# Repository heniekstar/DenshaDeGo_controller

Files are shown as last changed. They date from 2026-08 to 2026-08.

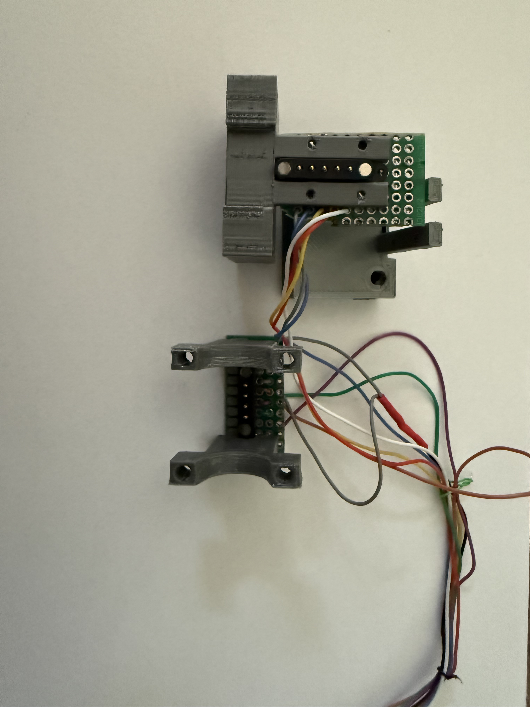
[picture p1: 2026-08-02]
pics/POGO_1.JPG

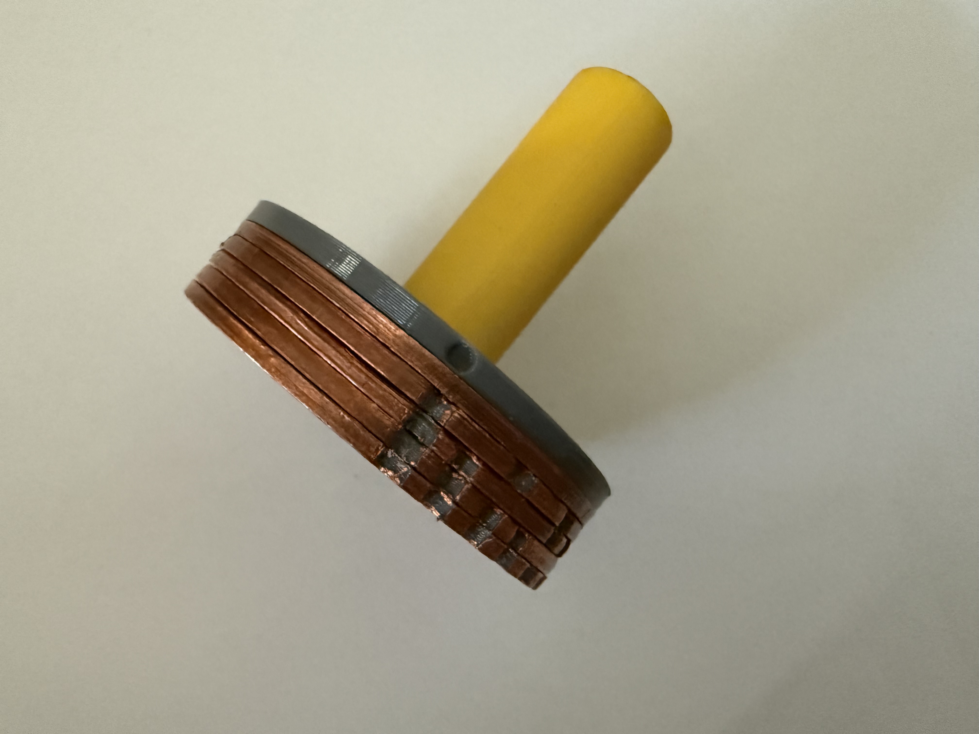
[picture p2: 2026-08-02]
pics/POGO_BREAK_WHEELS_2.JPG

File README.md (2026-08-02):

# DenshaDeGo_controller


3d printed recreation of Densha de Go! train controller using limit switches or pogo pins. 
Please remind: This is not a perfect controller. I've made this controller as a test for myself. 
I've made it also because I want to experience Densha de Go! on train controller and not on gamepad. 
Controller have some issues that require some additional work but I don't know if I could solve them.
I think this may bring new peoples to this games as it's lowers a barrier of entry.
Feel free to modify this controller

This could not be possible without Train controller database: https://traincontrollerdb.marcriera.cat/index.html

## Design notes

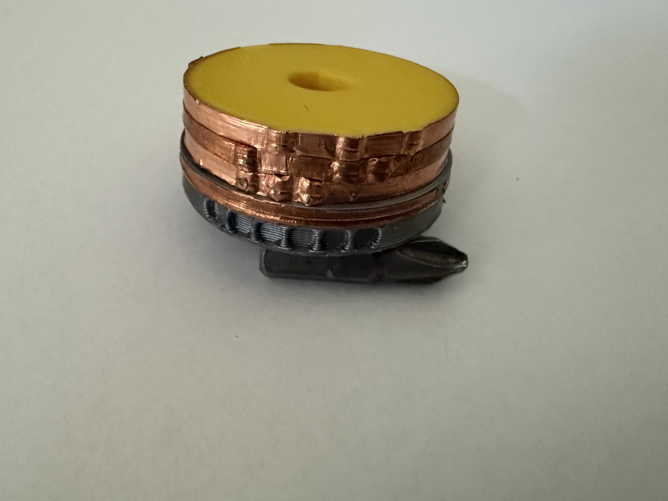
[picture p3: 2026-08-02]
pics/POGO_POWER_WHEELS_1.JPG

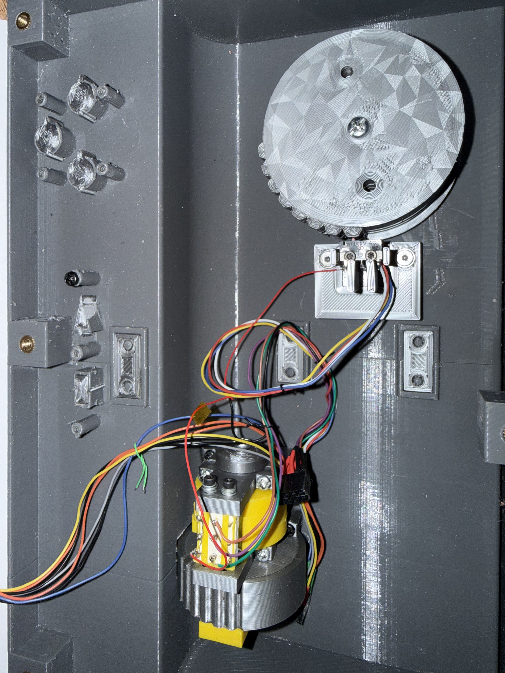
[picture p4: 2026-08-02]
pics/LIMIT_SWITCHES.JPG

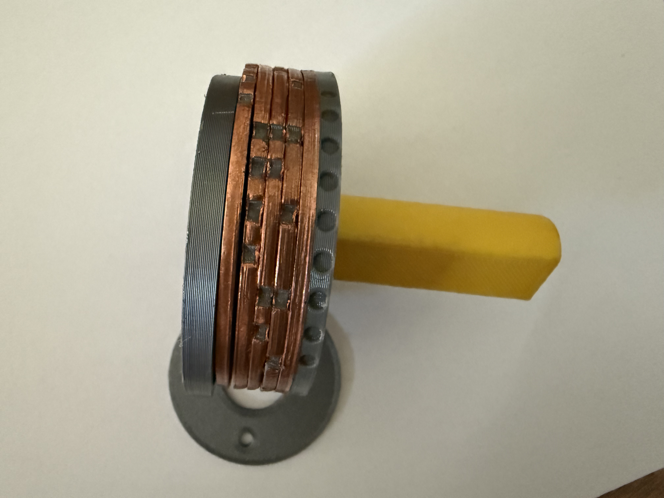
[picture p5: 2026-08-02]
pics/POGO_BREAK_WHEELS_1.JPG

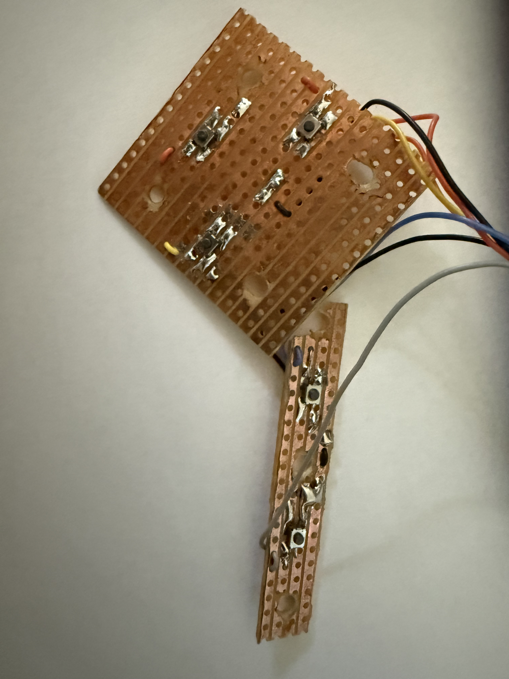
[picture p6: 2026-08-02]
pics/BUTTONS_PCBs.JPG

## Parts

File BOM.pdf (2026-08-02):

### BOM for End switch version

Id. Name | Pcs.
1. DDG_BREAK_SHAFT | 1
2. DDG_BRAKE_WHEEL_HAPTIC | 1
3. DDG_BRAKE_WHEEL_1 | 1
4. DDG_BRAKE_WHEEL_2 | 1
5. DDG_BRAKE_WHEEL_3 | 1
6. DDG_BRAKE_WHEEL_4 | 1
7. DDG_BREAK_HANDLE | 1
8. DDG_BREAK_HANDLE_BARREL | 1
9. DDG_BRAKE_SWITCH_HOUSING | 1
10. DDG_BREAK_SWITCH_HAPTIC | 1
11. DDG_POWER_SHAFT | 1
12. DDG_POWER_RING | 1
13. DDG_POWER_HANDLE_WHEEL | 1
14. DDG_POWER_WHEEL_1 | 1
15. DDG_POWER_WHEEL_2 | 1
16. DDG_POWER_WHEEL_3 | 1
17. DDG_POWER_END_CAP | 2
18. DDG_POWER_SWITCH_HOUSING | 1
19. DDG_TOP_HOUSING | 1
20. DDG_TOP_POWER_LOWER_SUPPORT | 3
21. DDG_POWER_ASSEMBLY | 1
22. DDG_TOP_POWER_UPPER_SUPPORT | 3
23. DDG_POWER_SWITCH_ASSEMBLY | 1
24. DDG_BREAK_ASSEMBLY | 1
25. DDG_BREAK_SWITCH_ASSEMBLY | 1
26. DDG_TOP&BOT_LINK | 4
27. DDG_POWER_HANDLE_ANGLE | 1
28. DDG_POWER_HANDLE_END_CAP | 1
29. DDG_TOP_SELECT _BUTTON | 1
30. DDG_TOP_START_BUTTON | 1
31. DDG_TOP_A_BUTTON | 1
32. DDG_TOP_B_BUTTON | 1
33. DDG_TOP_C_BUTTON | 1
34. DDG_BOTTON_SHELL | 1
35. DDG_BOT_STR_SEL_LINK | 1
36. DDG_TOP&BOT_LINK | 4
37. DDG_POWER_HAPTIC_HOLDER | 1
38. DDG_POWER_HAPTIC | 1
39. DDG_BOTTOM_START_SUPPORT | 1
40. DDG_TOP_ASSEMBLY | 1
41. DDG_BOTTOM_ASSEMBLY | 1
42. END SWITCH | 7
43. M4x14 Bolt (PH/PZ/HEX/TX) | 10
44. M2x30 screw with HEX head | 4
45. M2 NUT | 4
46. M2 washer (under head of M2 bolt, 4 per bolt | 12
47. Self-taping screw 3x8 or bolt M3x8 (up to M3x12) | 21
48. M3x12 (Can be shorter) | 9
49. Heat insert M4 | 6
50. Push button 3x4x2 | 6
51. Universal PCB | 1

52.

Thin guage wires (30AWG). They should not be a single core wires (8
colores minimum)

### Additional parts for POGO Version:

1. | DDG_BREAK_SHAFT (same as end switch version) | 1
2. | DDG_BRAKE_WHEEL_HAPTIC (same as end switch version) | 1
3. | DDG_POGO_BREAK_SPACER | 1
4. | DDG_POGO_BREAK_WHEEL_MAG | 2
5. | DDG_POGO_BREAK_WHEEL_0 | 1
6. | DDG_POGO_BREAK_WHEEL_1 | 1
7. | DDG_POGO_BREAK_WHEEL_2 | 1
8. | DDG_POGO_BREAK_WHEEL_3 | 1
9. | DDG_POGO_BREAK_WHEEL_4 | 1
10. DDG_POGO_BREAK_WHEEL_SUPPORT | 1
11. | DDG_BREAK_HANDLE (same as end switch version) | 1
12. DDG_BREAK_HANDLE_BARREL (same as end switch version) | 1
13. DDG_POWER_SHAFT (same as end switch version) | 1
14. DDG_POWER_RING (same as end switch version) | 1
15. DDG_POWER_HANDLE_WHEEL (same as end switch version) | 1
16. DDG_POGO_POWER_WHEEL_MAG | 2
17. DDG_POGO_POWER_WHEEL_0 | 1
18. DDG_POGO_POWER_WHEEL_1 | 1
19. DDG_POGO_POWER_WHEEL_2 | 1
20. DDG_POGO_POWER_WHEEL_3 | 1
21. DDG_POWER_END_CAP | 2
22. 4 pin POGO connector | 1
23. 5 pin POGO connector | 1

### For part number 42 – End switch use 12,8X6X6MM Limit switch. I’ve use this one: https://pl.aliexpress.com/item/1005005596552328.html?gatewayAdapt=glo2pol but this also should work:

https://www.tme.eu/pl/en/details/d2f-01/microswitches-snap-action/omron-electronic-components/

Just search for a limit switch that have the same dimensions.

### The pogo connector I’ve bought from this page: https://pl.aliexpress.com/item/1005010344694119.html?gatewayAdapt=glo2pol

Links to aliexpress are in Polish so adjust language to your country. I’ve ordered this parts long before EU tarfis. Maybe you can find same connectors on other sites.

For a push switch you can use any other design. It may be needed to trim „wings” on the buttons to make them fit.

### For Universal PCB I’ve used this kind of board:

### https://www.tme.eu/pl/en/details/rad-710-5/universal-pcbs/rademacher/710-5/

I’ve used this one because I’ve this one already. You can use other types of PCBs but it’s better to use board with 1.6mm thickness.

For connecting wires use a flexible wires as the are easier to handle inside the housing. I’ve recommend to use at least 8 colours for easier recognition what wire goes where. But I’m no gonna to stop you from using only one color for all cables.

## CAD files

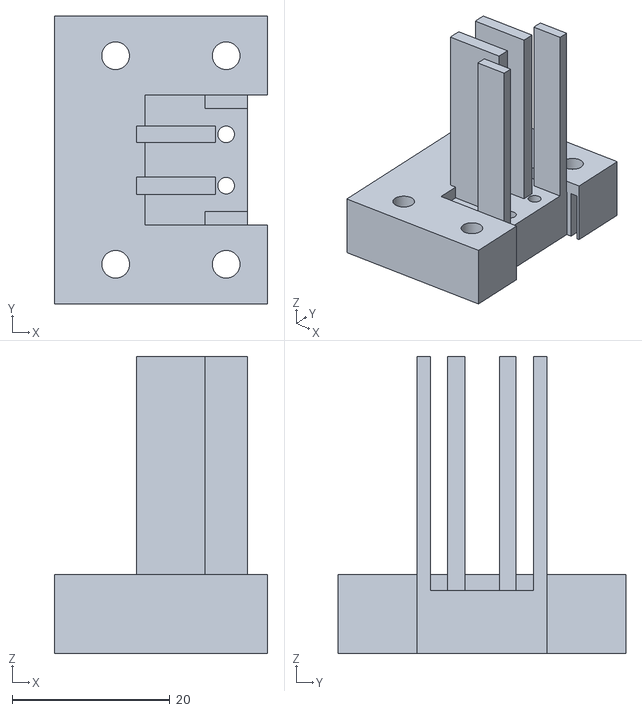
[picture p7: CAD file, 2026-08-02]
Limit_switch/DDG_BRAKE_SWITCH_HOUSING.stl
27.0 x 36.4 x 37.6

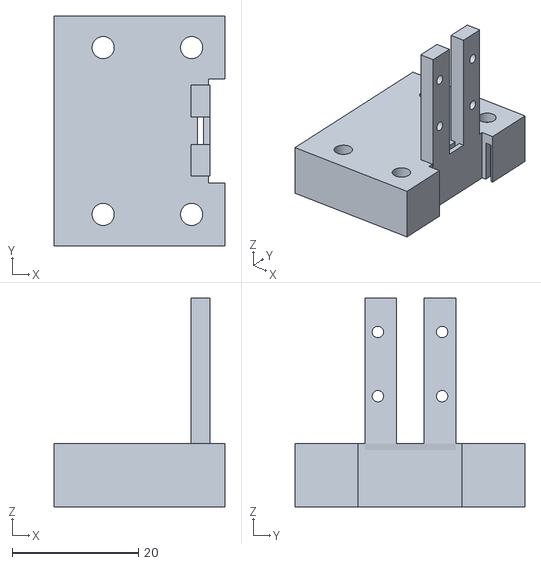
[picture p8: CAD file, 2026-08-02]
Pogo/DDG_POGO_BREAK_HOLDER.stl
27.0 x 36.4 x 33.0

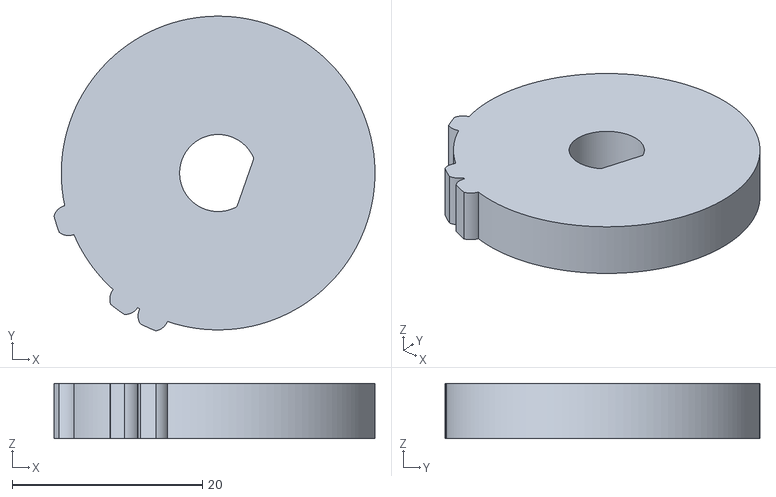
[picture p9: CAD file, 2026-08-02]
Limit_switch/DDG_POWER_WHEEL_2.stl
33.8 x 33.1 x 5.80

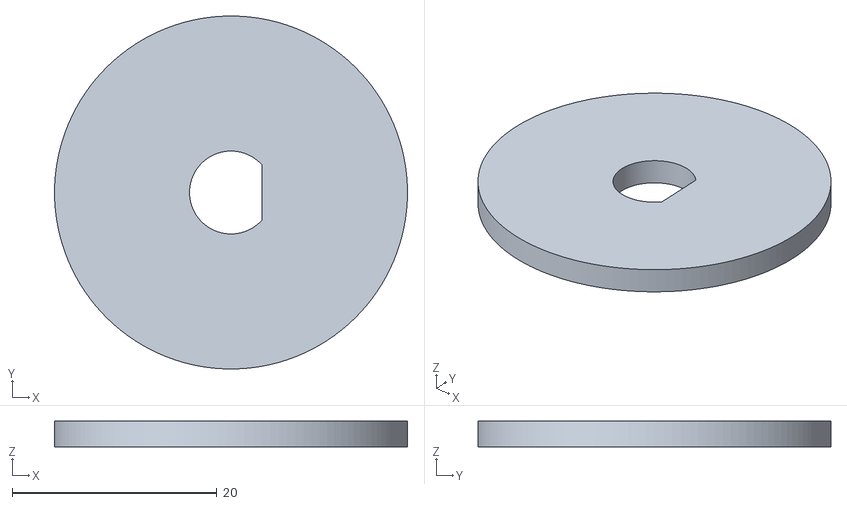
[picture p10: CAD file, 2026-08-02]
Pogo/DDG_POGO_POWER_WHEEL_0.stl
34.5 x 34.5 x 2.50

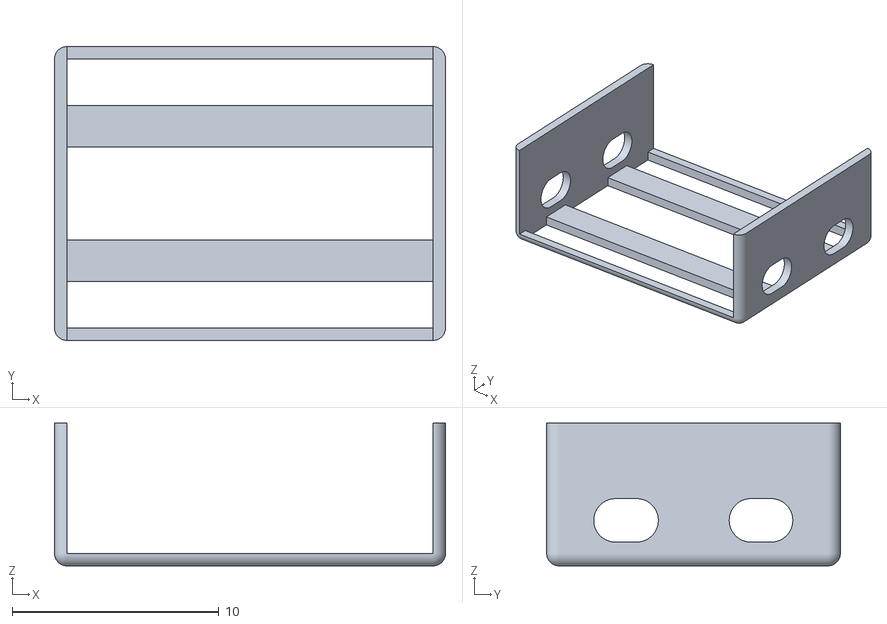
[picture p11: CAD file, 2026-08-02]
Limit_switch/DDG_POWER_SWITCH_HOUSING.stl
18.9 x 14.2 x 6.90

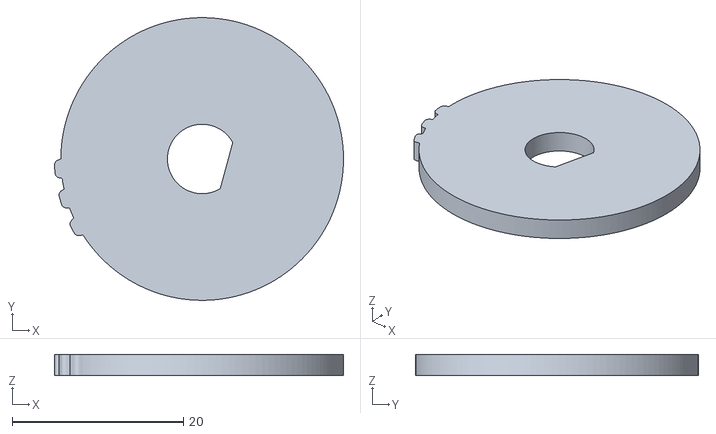
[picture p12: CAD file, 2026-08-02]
Pogo/DDG_POGO_POWER_WHEEL_3.stl
33.7 x 33.0 x 2.50

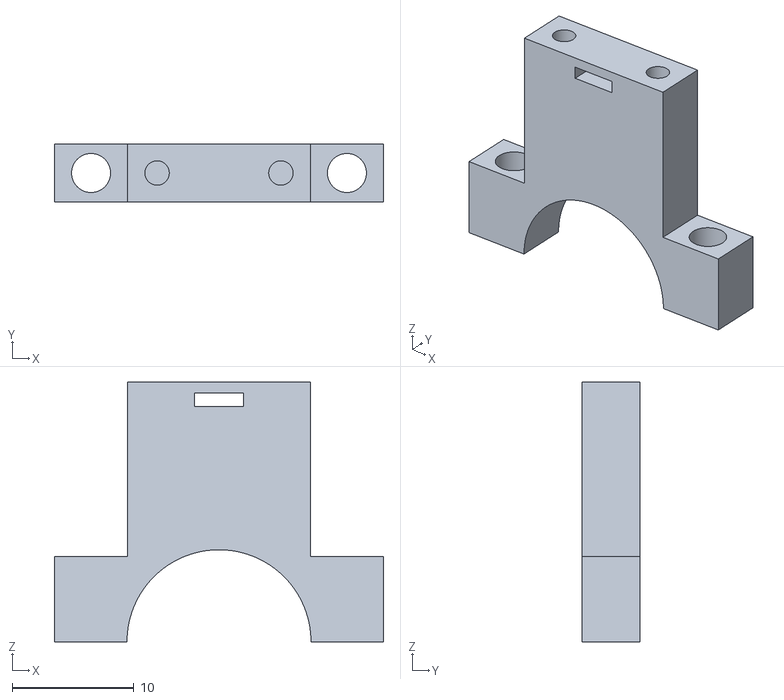
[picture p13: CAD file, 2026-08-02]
Pogo/DDG_POGO_POWER_UPPER_SUPPORT.stl
27.0 x 4.80 x 21.3

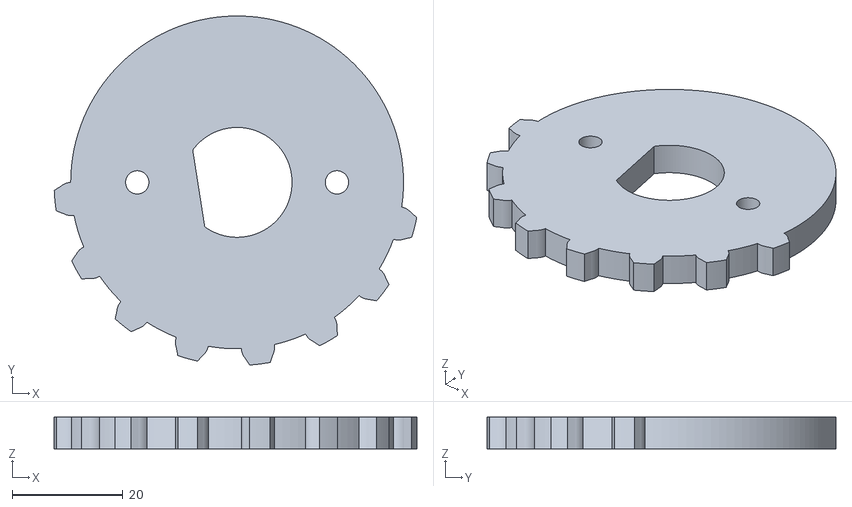
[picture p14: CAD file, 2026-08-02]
Limit_switch/DDG_BRAKE_WHEEL_1.stl
65.4 x 62.9 x 5.70

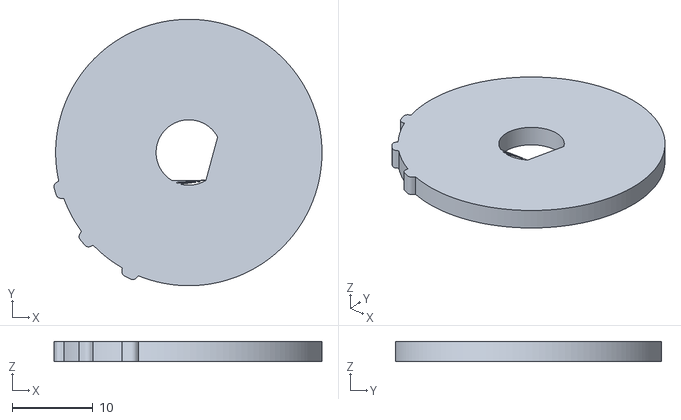
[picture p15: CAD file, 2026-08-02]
Pogo/DDG_POGO_POWER_WHEEL_1.stl
33.2 x 33.0 x 2.50

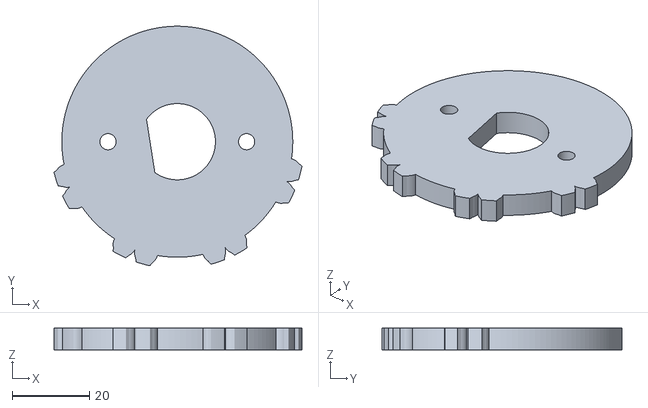
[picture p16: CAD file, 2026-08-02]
Limit_switch/DDG_BRAKE_WHEEL_2.stl
64.4 x 62.2 x 5.70

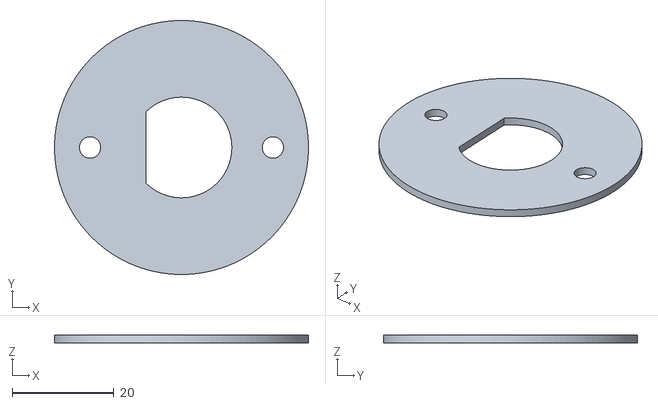
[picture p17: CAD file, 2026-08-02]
Pogo/DDG_POGO_BREAK_SPACER.stl
50.0 x 50.0 x 1.50

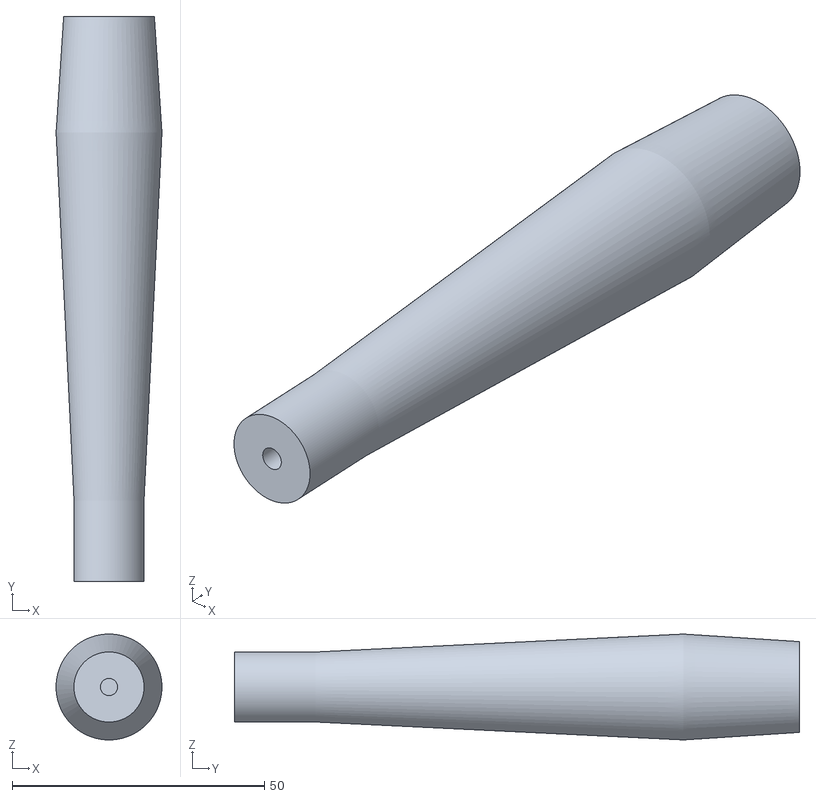
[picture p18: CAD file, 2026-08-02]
Limit_switch/DDG_BREAK_HANDLE.stl
21.0 x 112.0 x 21.0

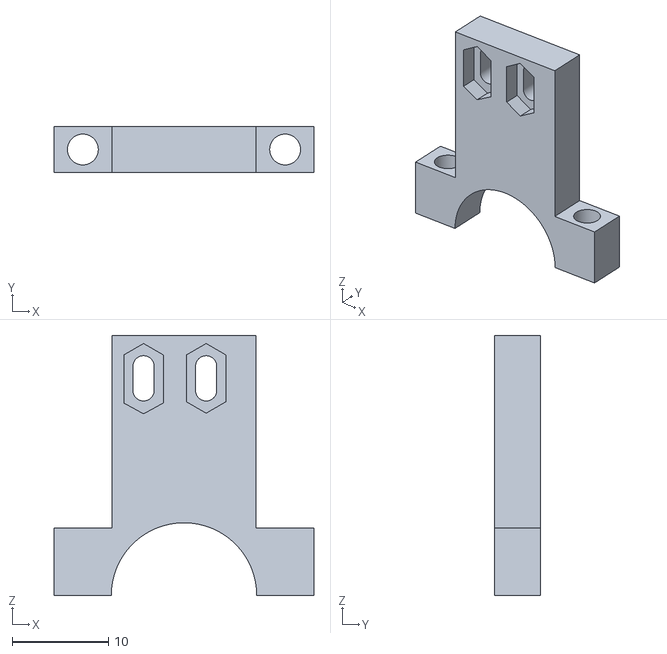
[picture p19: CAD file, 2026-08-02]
Limit_switch/DDG_TOP_POWER_UPPER_SUPPORT.stl
27.0 x 4.80 x 27.0

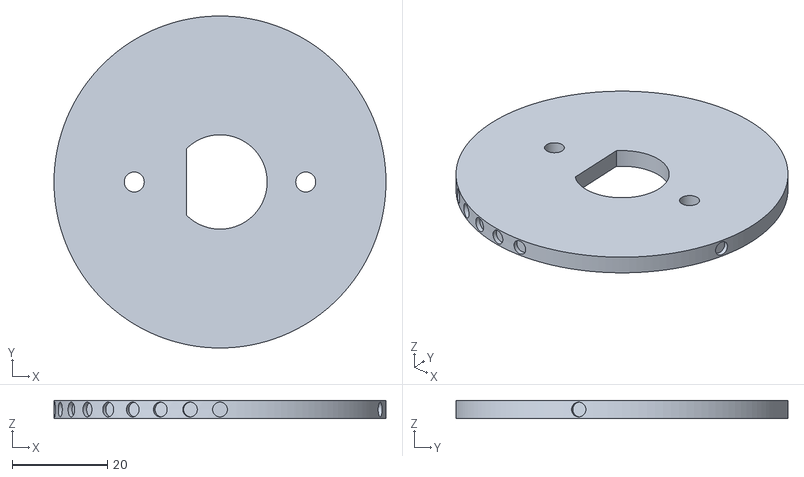
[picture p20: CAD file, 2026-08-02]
Pogo/DDG_POGO_BREAK_WHEEL_MAG.stl
69.7 x 69.7 x 3.80

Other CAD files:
Limit_switch/DDG_POWER_WHEEL_1.stl
Pogo/DDG_POGO_POWER_WHEEL_2.stl
Limit_switch/DDG_BRAKE_WHEEL_3.stl
Pogo/DDG_POGO_BREAK_WHEEL_2.stl
Limit_switch/DDG_BRAKE_WHEEL_4.stl
Limit_switch/DDG_POWER_WHEEL_3.stl
Pogo/DDG_BOTTOM_START_SUPPORT.stl
Pogo/DDG_BOTTON_SHELL-Slice.0.stl
Pogo/DDG_BOTTON_SHELL-Slice.1.stl
Pogo/DDG_BOTTON_SHELL.stl
Pogo/DDG_BOT_STR_SEL_LINK.stl
Pogo/DDG_BRAKE_WHEEL_HAPTIC.stl
Pogo/DDG_BREAK_GUIDE.stl
Pogo/DDG_BREAK_HANDLE_BARREL.stl
Pogo/DDG_BREAK_HANDLE_BARREL_GUIDE.stl
Pogo/DDG_BREAK_SHAFT.stl
Pogo/DDG_BREAK_SWITCH_HAPTIC.stl
Pogo/DDG_POGO_BREAK_WHEEL_0.stl
Pogo/DDG_POGO_BREAK_WHEEL_1.stl
Pogo/DDG_POGO_BREAK_WHEEL_3.stl
Pogo/DDG_POGO_BREAK_WHEEL_4.stl
Pogo/DDG_POGO_BREAK_WHEEL_SUPPORT.stl
Pogo/DDG_POGO_POWER_WHEEL_MAG.stl
Pogo/DDG_POWER_END_CAP.stl
Pogo/DDG_POWER_HANDLE_ANGLE.stl
Pogo/DDG_POWER_HANDLE_END_CAP.stl
Pogo/DDG_POWER_HANDLE_WHEEL.stl
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

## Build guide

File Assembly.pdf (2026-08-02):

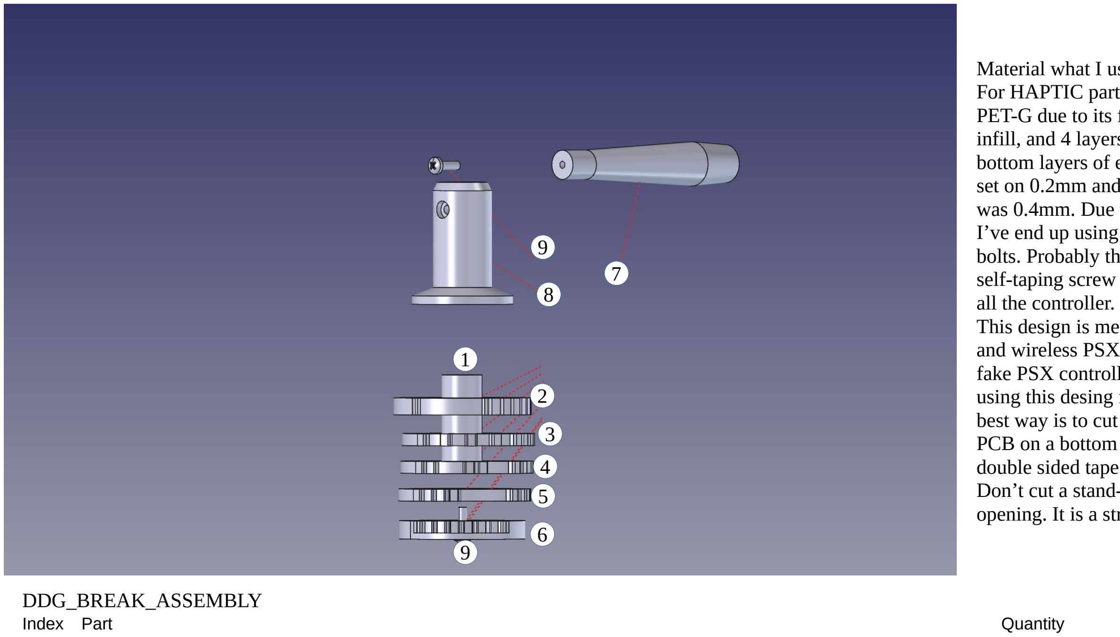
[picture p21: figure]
DDG_BREAK_ASSEMBLY; Index Part; Quantity; all the controller.

1. | DDG_BREAK_SHAFT | 1
2. | DDG_BRAKE_WHEEL_HAPTIC | 1
3. | DDG_BRAKE_WHEEL_1 | 1
4. | DDG_BRAKE_WHEEL_2 | 1
5. | DDG_BRAKE_WHEEL_3 | 1
6. | DDG_BRAKE_WHEEL_4 | 1
7. | DDG_BREAK_HANDLE (Installation after assembled in to the TOP_ASSEMBLY) | 1
8. | DDG_BREAK_HANDLE_BARREL (Installation after assembled in to the TOP_ASSEMBLY) | 1
9. | M4x14 (Installation after assembled in to the TOP_ASSEMBLY) | 2

I recommended to install DDG_BREAK_HANDLE and DDG_BREAK_HANDLE_BARREL after installing BREAK ASSEMBLY in to the TOP ASSEMBLY I’ve also designed a second version of DDG_BREAK_HANDLE_BARREL. This revision have a grove for a guide that have to be glued to DDG_TOP part. It was meant to eliminate a wobble of whole system but in reality there is almost no difference and wobble came from controller housing.

Material what I used for printing was a PLA. For HAPTIC part it may be better to use a PET-G due to its flexibility. I’ve used a 40% infill, and 4 layers walls. Same for top and bottom layers of every print. Layer high was set on 0.2mm and the nozzle that I’ve used was 0.4mm. Due to my 3d printer accuracy I’ve end up using M3 bolts in place of M4 bolts. Probably the best solution is to used self-taping screw (or screws for plastics) for

This design is ment for a fake N64 controller and wireless PSX controller. I think wired fake PSX controller is also fine. In case of using this desing for other controller PCBs the best way is to cut stand off for Controller
PCB on a bottom housing. Then just used double sided tape to hold PCB in place. Don’t cut a stand-off closest to the wall with opening. It is a strain relief for cable.

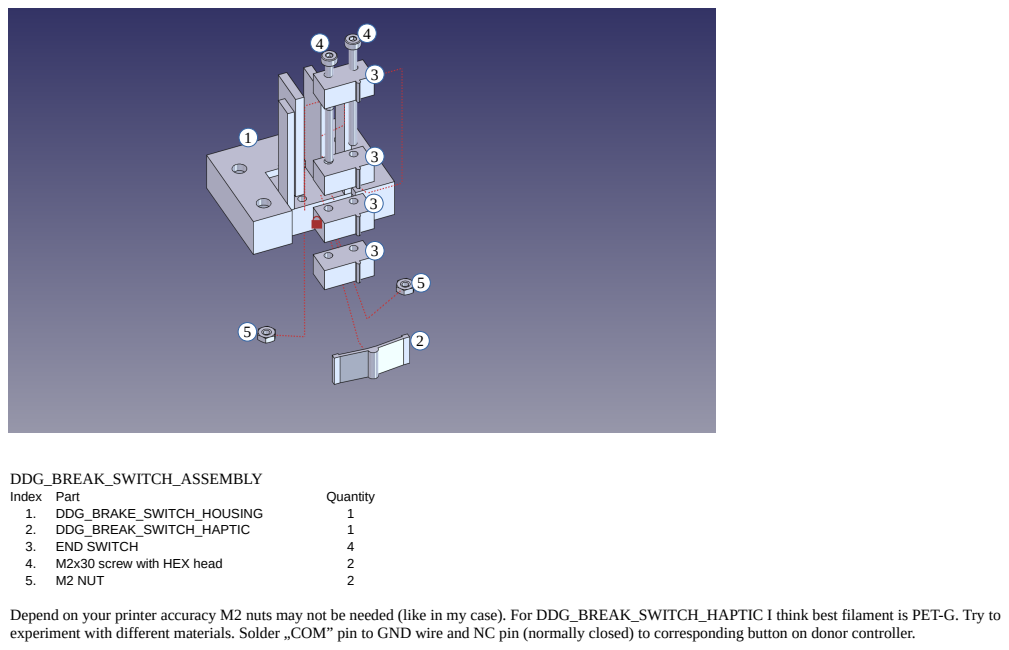
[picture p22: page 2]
Index Part; Quantity; DDG_BRAKE_SWITCH_HOUSING; DDG_BREAK_SWITCH_HAPTIC; END SWITCH; M2x30 screw with HEX head; M2 NUT

DDG_BREAK_SWITCH_ASSEMBLY
Depend on your printer accuracy M2 nuts may not be needed (like in my case). For DDG_BREAK_SWITCH_HAPTIC I think best filament is PET-G. Try to
experiment with different materials. Solder „COM” pin to GND wire and NC pin (normally closed) to corresponding button on donor controller.

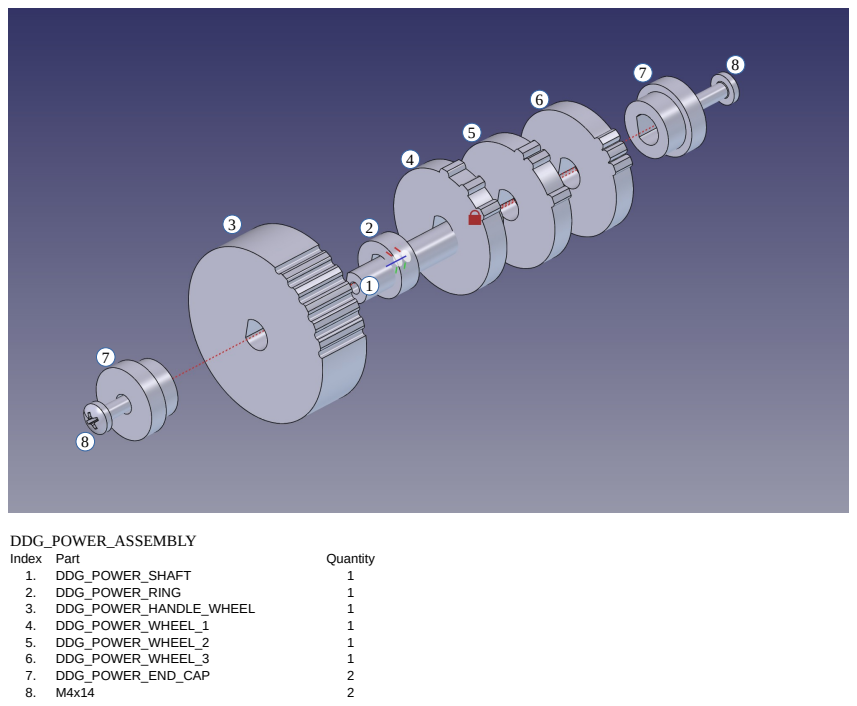
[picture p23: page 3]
DDG_POWER_ASSEMBLY; Index Part; Quantity; DDG_POWER_SHAFT; DDG_POWER_RING; DDG_POWER_HANDLE_WHEEL; DDG_POWER_WHEEL_1; DDG_POWER_WHEEL_2; DDG_POWER_WHEEL_3; DDG_POWER_END_CAP

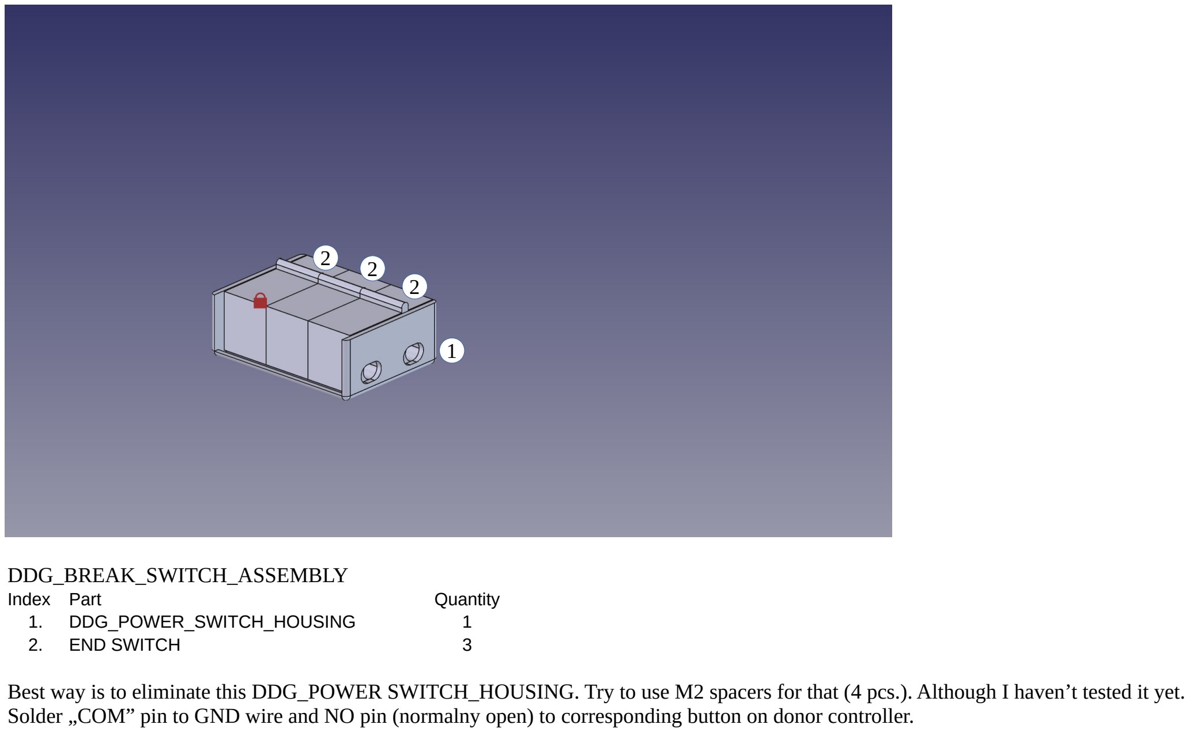
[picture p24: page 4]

DDG_BREAK_SWITCH_ASSEMBLY
Index Part | Quantity
1. | DDG_POWER_SWITCH_HOUSING | 1
2. | END SWITCH | 3

Best way is to eliminate this DDG_POWER SWITCH_HOUSING. Try to use M2 spacers for that (4 pcs.). Although I haven’t tested it yet. Solder „COM” pin to GND wire and NO pin (normalny open) to corresponding button on donor controller.

1

2
2
2

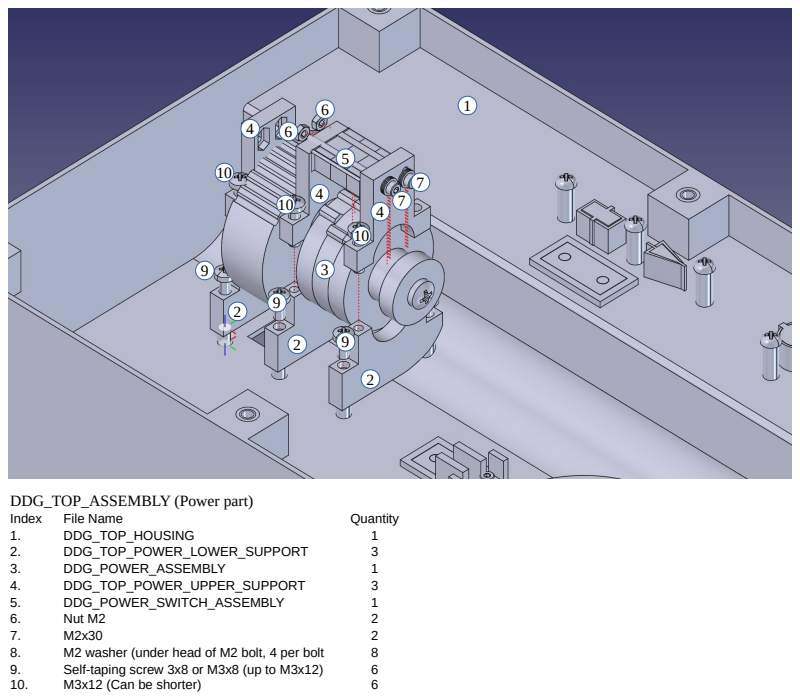
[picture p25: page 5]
DDG_TOP_ASSEMBLY (Power part); Index; File Name; Quantity; DDG_TOP_HOUSING; DDG_TOP_POWER_LOWER_SUPPORT; DDG_POWER_ASSEMBLY; DDG_TOP_POWER_UPPER_SUPPORT; DDG_POWER_SWITCH_ASSEMBLY; Nut M2; M2 washer (under head of M2 bolt, 4 per bolt; Self-taping screw 3x8 or M3x8 (up to M3x12); M3x12 (Can be shorter)

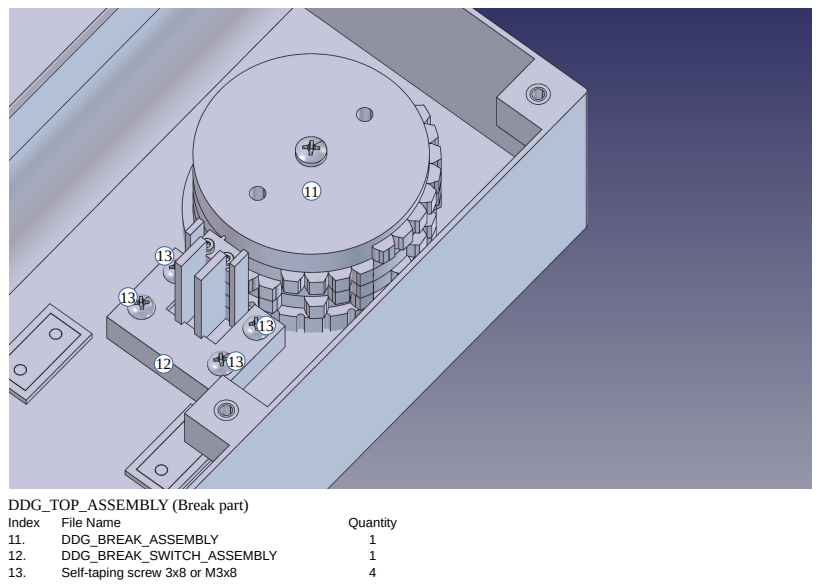
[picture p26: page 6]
DDG_TOP_ASSEMBLY (Break part); Index; File Name; Quantity; DDG_BREAK_ASSEMBLY; DDG_BREAK_SWITCH_ASSEMBLY; Self-taping screw 3x8 or M3x8

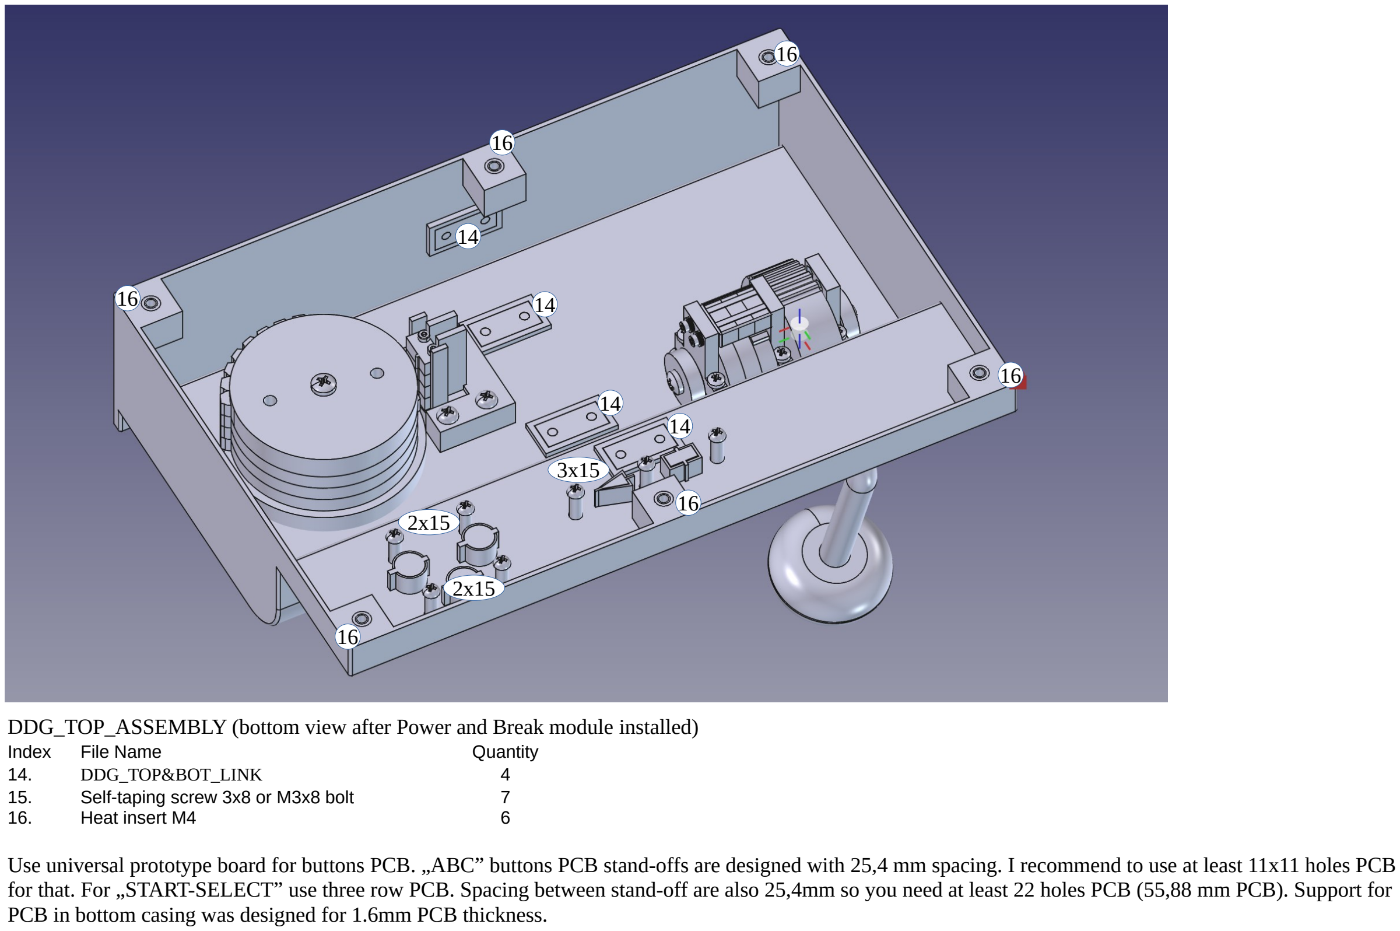
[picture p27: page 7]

DDG_TOP_ASSEMBLY (bottom view after Power and Break module installed)
Index | File Name | Quantity
14. | DDG_TOP&BOT_LINK | 4
15. | Self-taping screw 3x8 or M3x8 bolt | 7
16. | Heat insert M4 | 6

Use universal prototype board for buttons PCB. „ABC” buttons PCB stand-offs are designed with 25,4 mm spacing. I recommend to use at least 11x11 holes PCB for that. For „START-SELECT” use three row PCB. Spacing between stand-off are also 25,4mm so you need at least 22 holes PCB (55,88 mm PCB). Support for PCB in bottom casing was designed for 1.6mm PCB thickness.

14

14

14
14

3x15

16

16

16

16

16

16
2x15

2x15

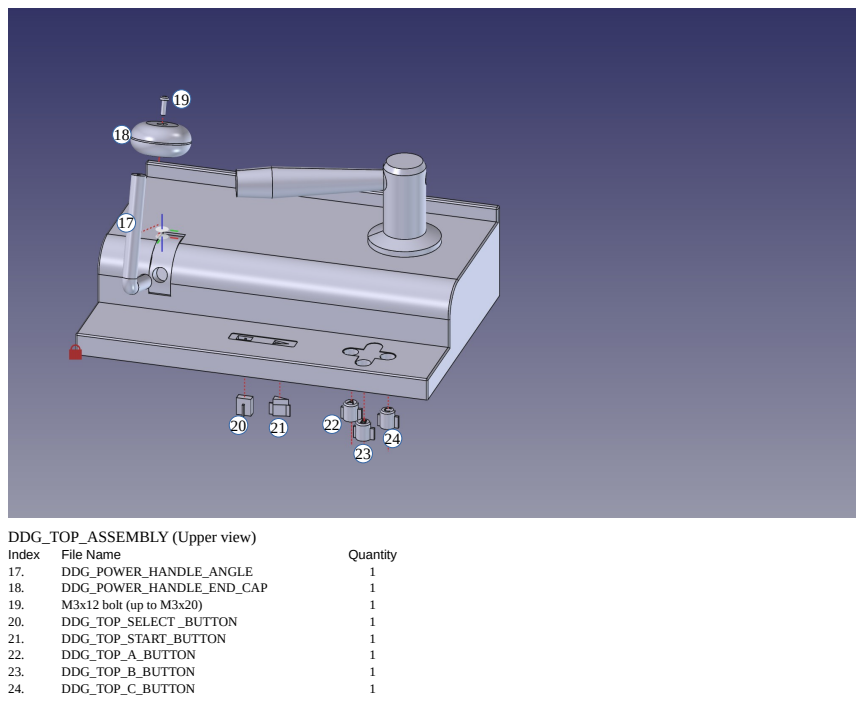
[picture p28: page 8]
DDG_TOP_ASSEMBLY (Upper view); Index; File Name; Quantity; DDG_POWER_HANDLE_ANGLE; DDG_POWER_HANDLE_END_CAP; M3x12 bolt (up to M3x20); DDG_TOP_SELECT _BUTTON; DDG_TOP_START_BUTTON; DDG_TOP_A_BUTTON; DDG_TOP_B_BUTTON; DDG_TOP_C_BUTTON

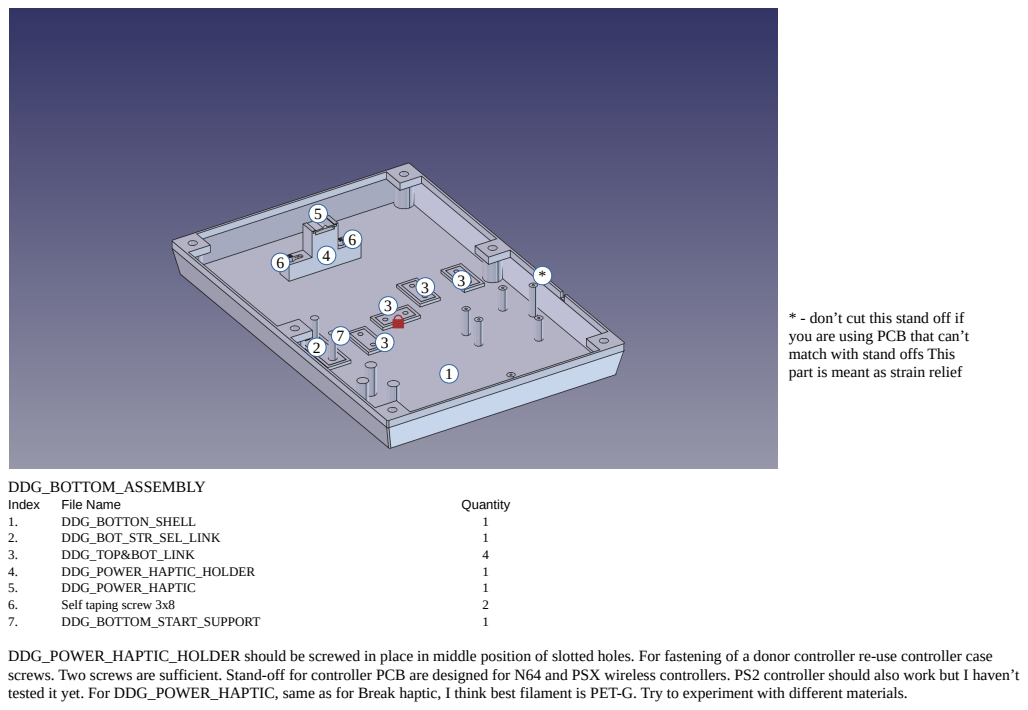
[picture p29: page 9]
Index; File Name; Quantity; DDG_BOTTON_SHELL; DDG_BOT_STR_SEL_LINK; DDG_TOP&BOT_LINK; DDG_POWER_HAPTIC_HOLDER; DDG_POWER_HAPTIC; Self taping screw 3x8; DDG_BOTTOM_START_SUPPORT

* - don’t cut this stand off if
you are using PCB that can’t
match with stand offs This
part is meant as strain relief

DDG_BOTTOM_ASSEMBLY
DDG_POWER_HAPTIC_HOLDER should be screwed in place in middle position of slotted holes. For fastening of a donor controller re-use controller case
screws. Two screws are sufficient. Stand-off for controller PCB are designed for N64 and PSX wireless controllers. PS2 controller should also work but I haven’t
tested it yet. For DDG_POWER_HAPTIC, same as for Break haptic, I think best filament is PET-G. Try to experiment with different materials.

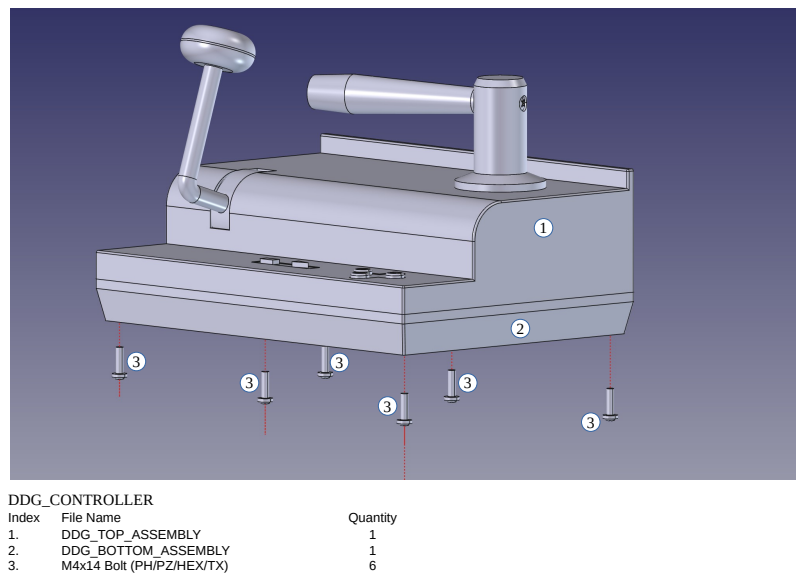
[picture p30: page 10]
DDG_CONTROLLER; Index; File Name; Quantity; DDG_TOP_ASSEMBLY; DDG_BOTTOM_ASSEMBLY; M4x14 Bolt (PH/PZ/HEX/TX)

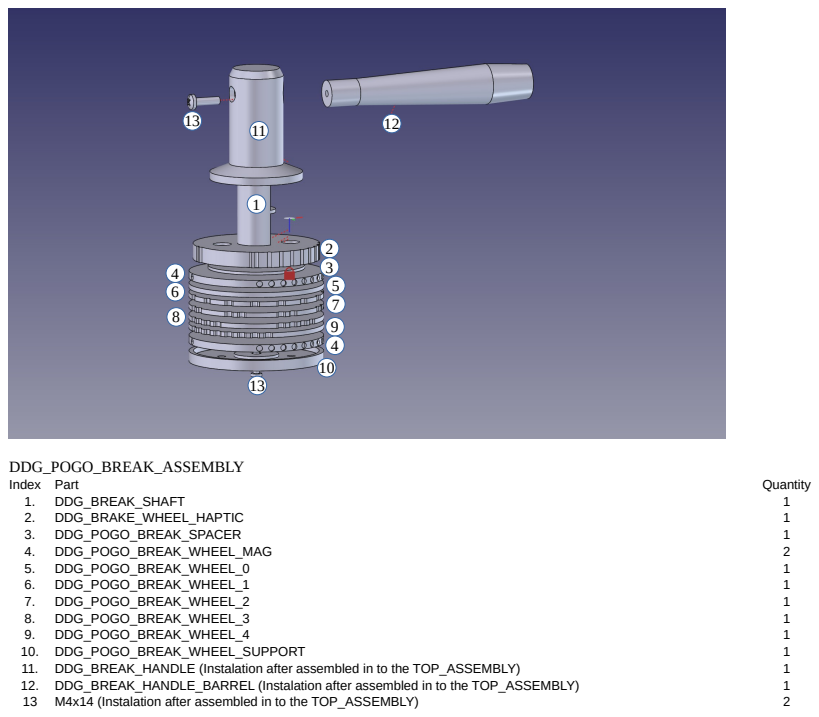
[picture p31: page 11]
DDG_POGO_BREAK_ASSEMBLY; Index Part; Quantity; DDG_BREAK_SHAFT; DDG_BRAKE_WHEEL_HAPTIC; DDG_POGO_BREAK_SPACER; DDG_POGO_BREAK_WHEEL_MAG; DDG_POGO_BREAK_WHEEL_0; DDG_POGO_BREAK_WHEEL_1; DDG_POGO_BREAK_WHEEL_2; DDG_POGO_BREAK_WHEEL_3; DDG_POGO_BREAK_WHEEL_4; 10. DDG_POGO_BREAK_WHEEL_SUPPORT; 11. DDG_BREAK_HANDLE (Instalation after assembled in to the TOP_ASSEMBLY); 12. DDG_BREAK_HANDLE_BARREL (Instalation after assembled in to the TOP_ASSEMBLY)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

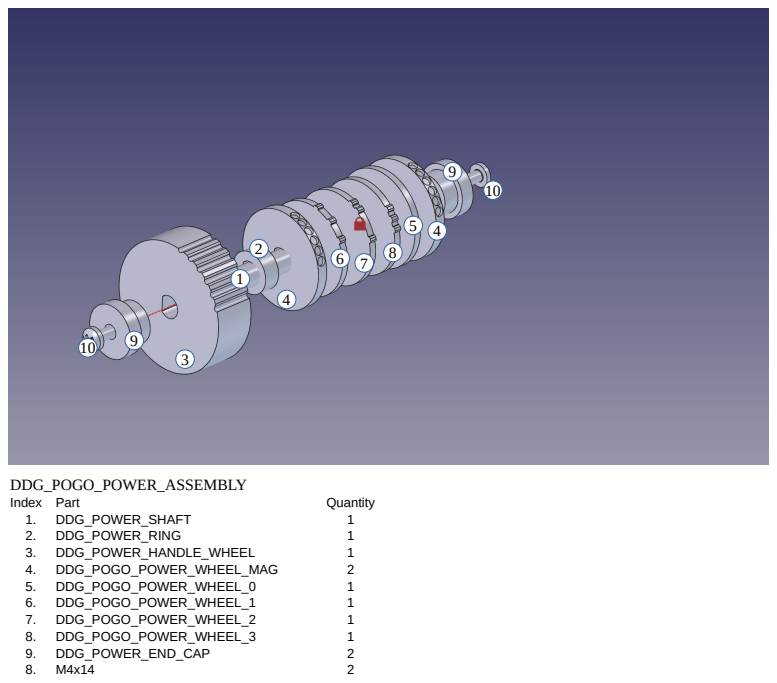
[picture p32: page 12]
DDG_POGO_POWER_ASSEMBLY; Index Part; Quantity; DDG_POWER_SHAFT; DDG_POWER_RING; DDG_POWER_HANDLE_WHEEL; DDG_POGO_POWER_WHEEL_MAG; DDG_POGO_POWER_WHEEL_0; DDG_POGO_POWER_WHEEL_1; DDG_POGO_POWER_WHEEL_2; DDG_POGO_POWER_WHEEL_3; DDG_POWER_END_CAP

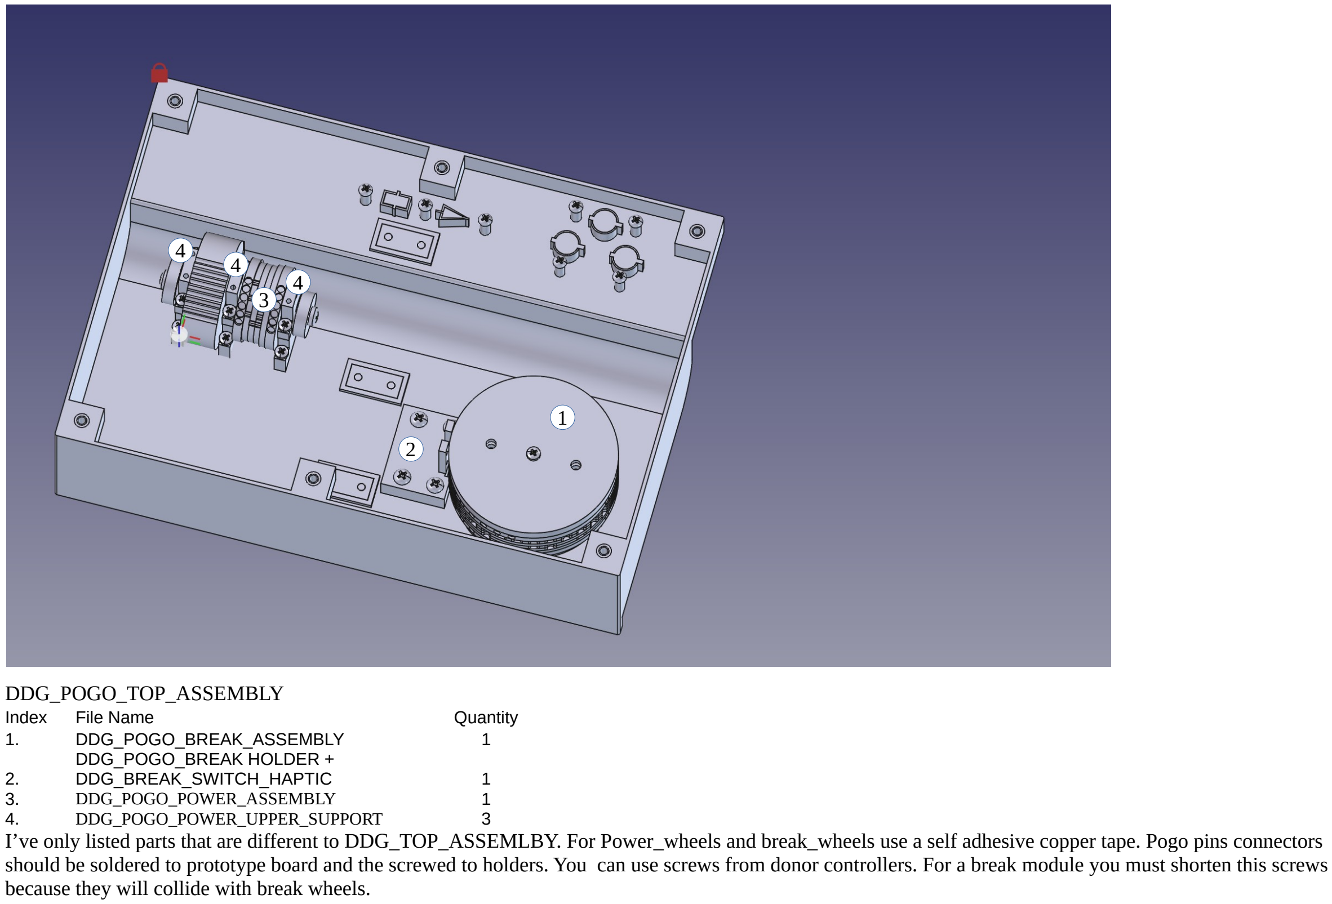
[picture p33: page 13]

DDG_POGO_TOP_ASSEMBLY
Index | File Name | Quantity
1. | DDG_POGO_BREAK_ASSEMBLY | 1
2. | DDG_POGO_BREAK HOLDER +
| DDG_BREAK_SWITCH_HAPTIC | 1
3. | DDG_POGO_POWER_ASSEMBLY | 1
4. | DDG_POGO_POWER_UPPER_SUPPORT | 3
I’ve only listed parts that are different to DDG_TOP_ASSEMLBY. For Power_wheels and break_wheels use a self adhesive copper tape. Pogo pins connectors should be soldered to prototype board and the screwed to holders. You can use screws from donor controllers. For a break module you must shorten this screws because they will collide with break wheels.

1
2

3

4

4

4

This project is not perfect. It have some problem that I haven’t figure out. There is a problem with „emergency” break position (the last position on break). Switch housing is tilt back and not all end switches are pressed. Problem may lay in to stiff “SWITCH HAPTIC” part, but also position of switch assembly. Try different position (further or closer to Break Assembly). There is no end stops to stop handles from moving out of range.
For connecting limit switches to gamepad PCB use in-line connectors. It’s not necessary but helps during disassembling the controller. For my case I’ve used a pice of prototype PCB and gold-pins. You need at least 7x2 connector (14 positions).

For pin-out how to connect controller PCB to switches and buttons use this guide: https://traincontrollerdb.marcriera.cat/hardware/tech/console_controllers/index.html (https://traincontrollerdb.marcriera.cat/hardware/tech/console_controllers/index.html)

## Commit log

2026-08-02 Limit switch version
    [DDG_BOTTOM_START_SUPPORT.stl, DDG_BOTTON_SHELL-Slice.0.stl, DDG_BOTTON_SHELL-Slice.1.stl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]
2026-08-02 Create Limit switch
2026-08-02 Pogo version added
    [DDG_BOTTOM_START_SUPPORT.stl, DDG_BOTTON_SHELL-Slice.0.stl, DDG_BOTTON_SHELL-Slice.1.stl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]
2026-08-02 Added BOM and Assembly files
